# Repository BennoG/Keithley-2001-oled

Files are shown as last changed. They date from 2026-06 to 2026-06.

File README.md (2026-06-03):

# Keithley-2001-oled

This is my attempt to put a OLED display in a Keithley 2001 - 2400 - 7000
This is for the almost unobtainable dot matrix VFD display.

At this moment only tested on a raspberry PI and raspberry PI pico
with a Keithley 2001 meter.

For the font I have added all the display test characters and also the bargrap characters.



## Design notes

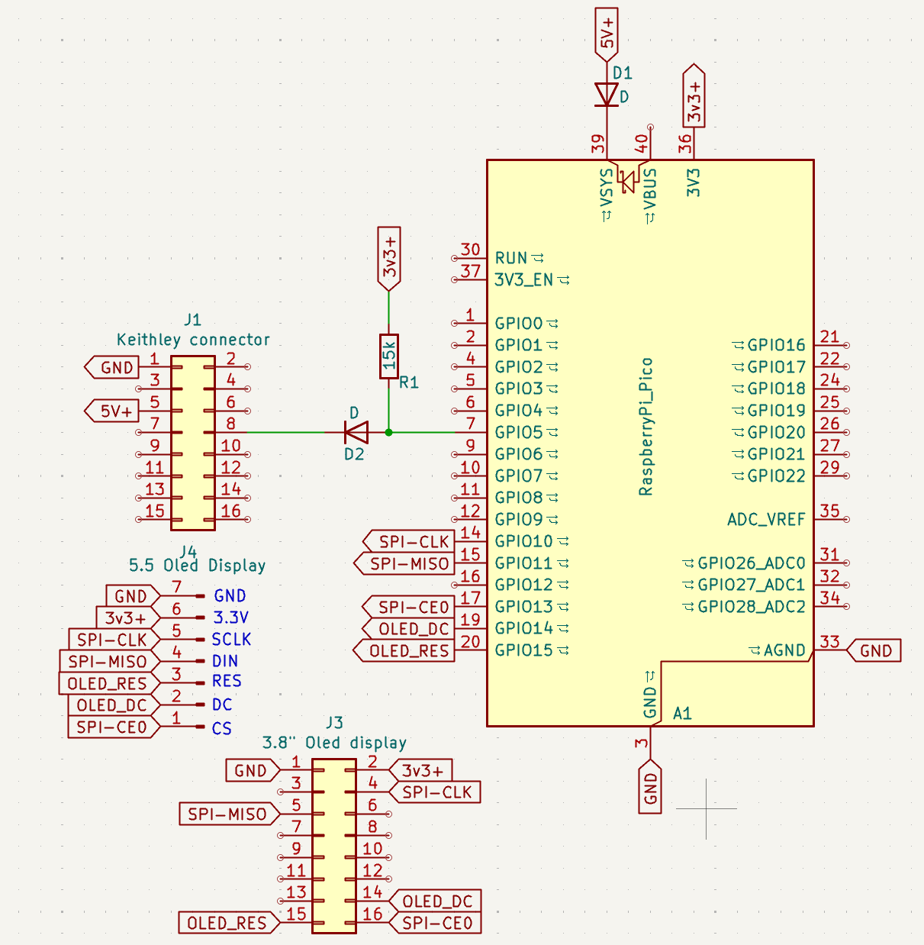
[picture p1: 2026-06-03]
pcb/keithley-2001-display-handwire/simple schema.png

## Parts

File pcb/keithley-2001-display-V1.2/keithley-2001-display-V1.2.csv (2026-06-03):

Reference | Value | Datasheet | Footprint | Qty | DNP | JLCPCB | Sim.Device
A1 | RaspberryPi_Pico | https://datasheets.raspberrypi.com/pico/pico-datasheet.pdf | Module:RaspberryPi_Pico_Common_Unspecified | 1 | DNP | DNP
C1,C2,C4,C5,C6 | 100n/50V |  | Capacitor_SMD:C_0402_1005Metric | 5 |  | C307331 | basic
C3 | 10u 100V |  | Capacitor_SMD:CP_Elec_8x6.2 | 1 |  | C346985 | extended
D1 | B360A-13-F | http://www.farnell.com/datasheets/2238505.pdf | Diode_SMD:D_SMA | 1 |  | C14996 | basic
H1,H2,H3 | MountingHole |  | MountingHole:MountingHole_2.7mm_M2.5 | 3 | DNP | DNP
J1 | Kdisp |  | Connector_PinHeader_2.54mm:PinHeader_2x08_P2.54mm_Vertical | 1 | DNP | DNP
J2 | Kcpu |  | Connector_PinHeader_2.54mm:PinHeader_2x08_P2.54mm_Vertical | 1 | DNP | DNP
J3 | 3.8" Oled display |  | Connector_PinHeader_2.54mm:PinHeader_2x08_P2.54mm_Vertical | 1 | DNP | DNP
J4 | 5.5 Oled Display |  | Connector_PinHeader_2.54mm:PinHeader_1x07_P2.54mm_Vertical | 1 | DNP | DNP
J5 | Conn_01x03_Pin |  | Connector_PinHeader_2.54mm:PinHeader_1x03_P2.54mm_Vertical | 1 | DNP | DNP
R1 | 15k |  | Resistor_SMD:R_0201_0603Metric | 1 |  | C22809 | basic
U1,U3 | 74LVC2T45DC | https://assets.nexperia.com/documents/data-sheet/74LVC_LVCH2T45.pdf | Package_SO:VSSOP-8_2.3x2mm_P0.5mm | 2 |  | C15741 | extended
U2 | 74LVC1G08 | https://www.ti.com/lit/ds/symlink/sn74lvc1g08.pdf | Package_TO_SOT_SMD:SOT-23-5 | 1 |  | C7666 | extended

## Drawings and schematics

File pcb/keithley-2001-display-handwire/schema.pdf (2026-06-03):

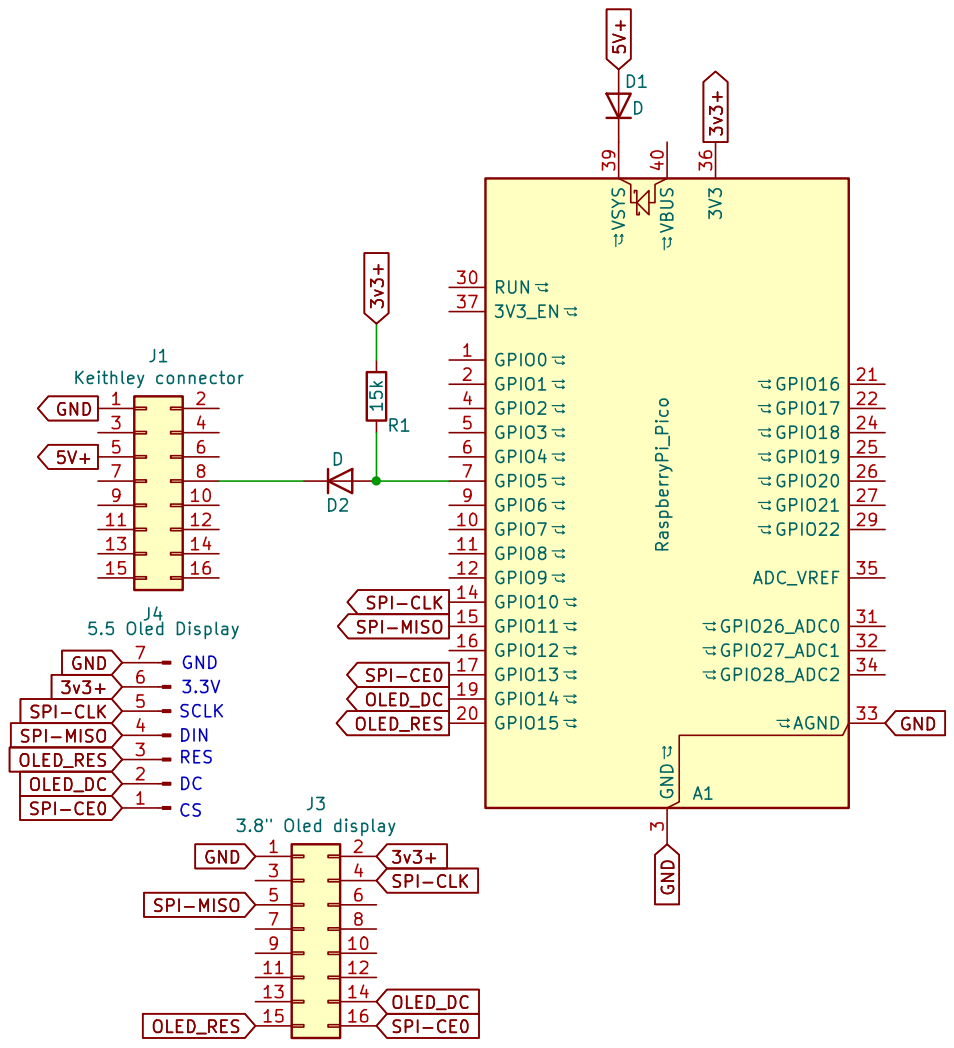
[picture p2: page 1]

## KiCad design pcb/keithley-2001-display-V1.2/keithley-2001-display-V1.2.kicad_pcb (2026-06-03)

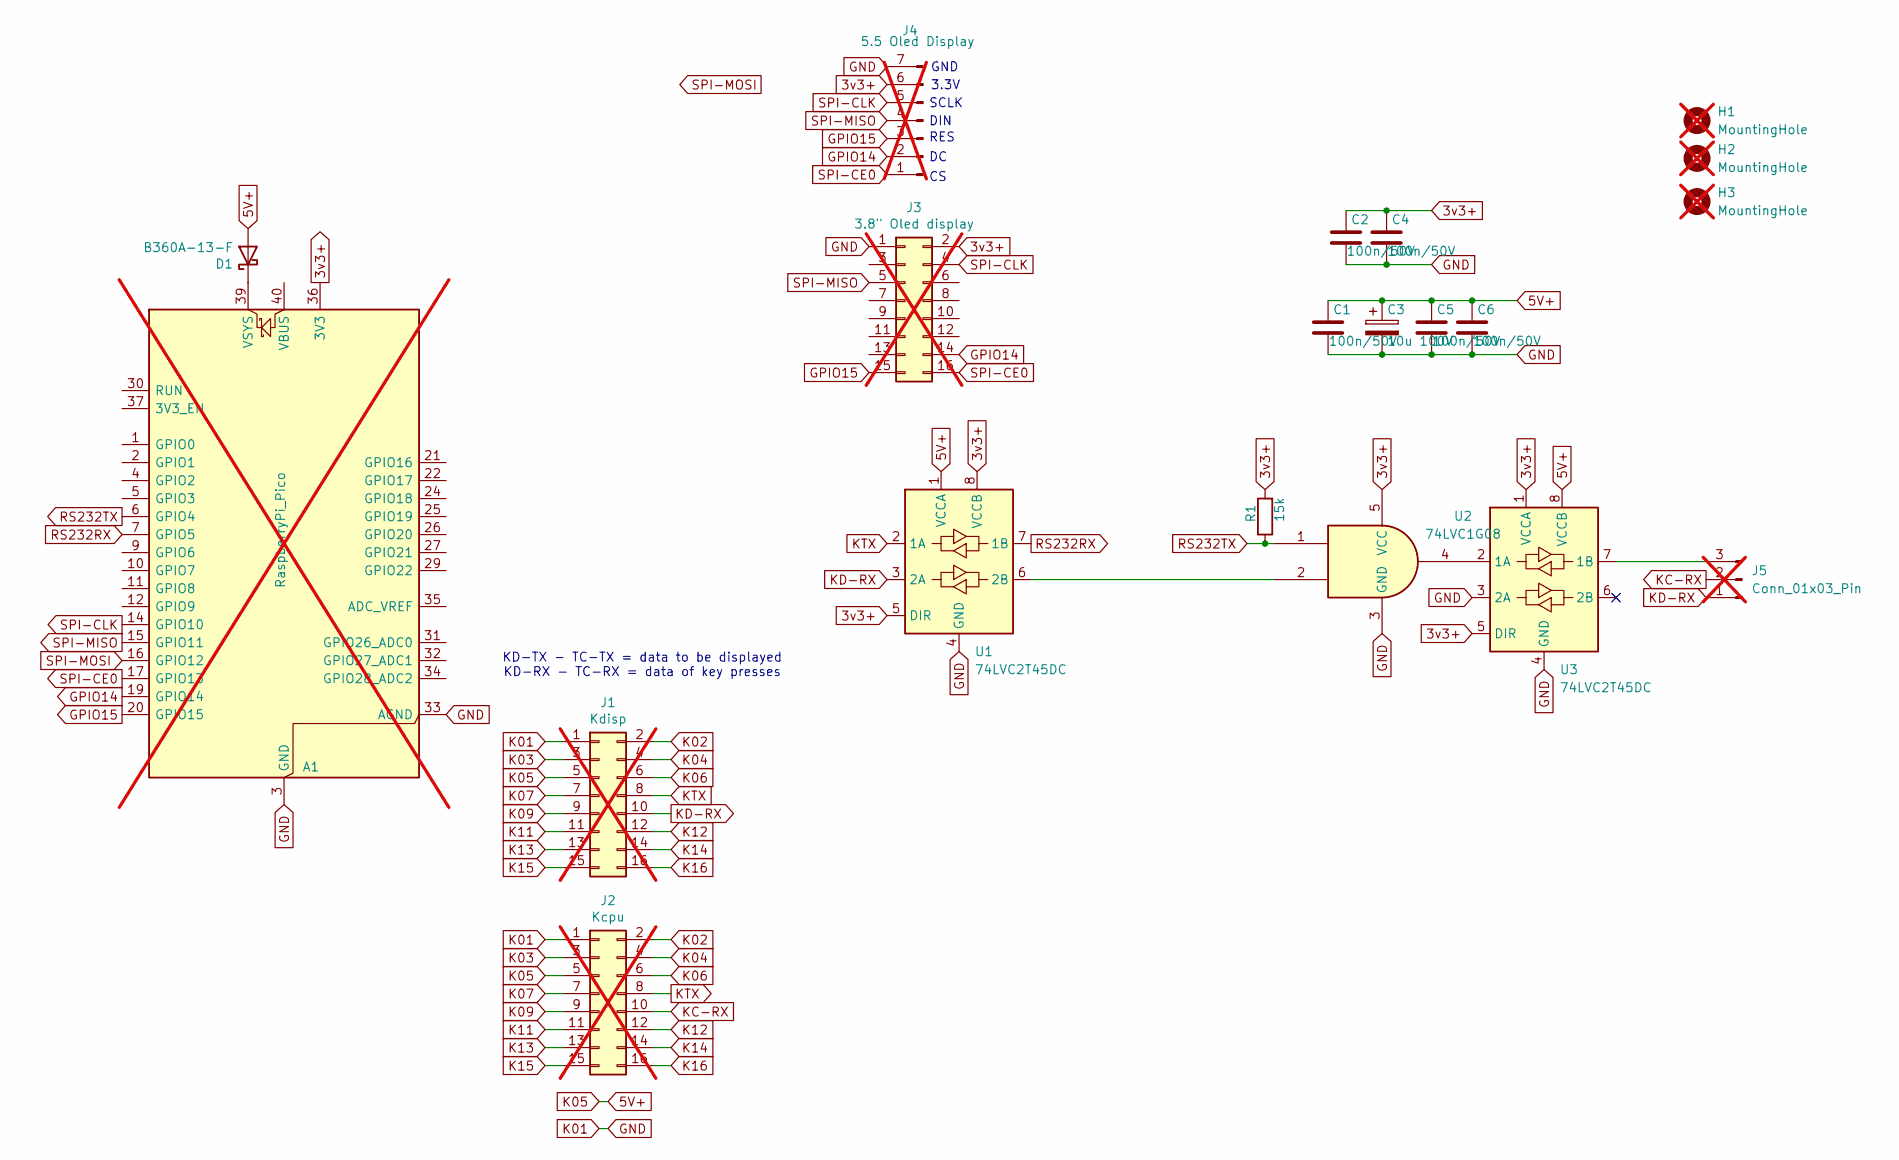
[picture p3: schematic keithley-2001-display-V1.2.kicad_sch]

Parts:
A1: RaspberryPi_Pico; RaspberryPi_Pico_Common_Unspecified; JLCPCB DNP; not fitted
C1, C2, C4, C5, C6: 100n/50V; C_0402_1005Metric; JLCPCB C307331
C3: 10u 100V; CP_Elec_8x6.2; JLCPCB C346985
D1: B360A-13-F; D_SMA; JLCPCB C14996
H1, H2, H3: MountingHole; MountingHole_2.7mm_M2.5; JLCPCB DNP; not fitted
J1: Kdisp; PinHeader_2x08_P2.54mm_Vertical; JLCPCB DNP; not fitted
J2: Kcpu; PinHeader_2x08_P2.54mm_Vertical; JLCPCB DNP; not fitted
J3: 3.8" Oled display; PinHeader_2x08_P2.54mm_Vertical; JLCPCB DNP; not fitted
J4: 5.5 Oled Display; PinHeader_1x07_P2.54mm_Vertical; JLCPCB DNP; not fitted
J5: Conn_01x03_Pin; PinHeader_1x03_P2.54mm_Vertical; JLCPCB DNP; not fitted
R1: 15k; R_0201_0603Metric; JLCPCB C22809
U1, U3: 74LVC2T45DC; VSSOP-8_2.3x2mm_P0.5mm; JLCPCB C15741
U2: 74LVC1G08; SOT-23-5; JLCPCB C7666

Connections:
3v3+: A1.36 (3V3), C2.1, C4.1, J3.2, J4.6, R1.2, U1.5 (DIR), U1.8 (VCCB), U2.5 (VCC), U3.1 (VCCA), U3.5 (DIR)
5V+: C1.1, C3.1, C5.1, C6.1, D1.2 (A), J1.5, J2.5, U1.1 (VCCA), U3.8 (VCCB)
GND: A1.3 (GND), A1.8 (GND), A1.13 (GND), A1.18 (GND), A1.23 (GND), A1.28 (GND), A1.33 (AGND), A1.38 (GND), C1.2, C2.2, C3.2, C4.2, C5.2, C6.2, J1.1, J2.1, J3.1, J4.7, U1.4 (GND), U2.3 (GND), U3.3 (2A), U3.4 (GND)
GPIO14: A1.19 (GPIO14), J3.14, J4.2
GPIO15: A1.20 (GPIO15), J3.15, J4.3
K02: J1.2, J2.2
K03: J1.3, J2.3
K04: J1.4, J2.4
K06: J1.6, J2.6
K07: J1.7, J2.7
K09: J1.9, J2.9
K11: J1.11, J2.11
K12: J1.12, J2.12
K13: J1.13, J2.13
K14: J1.14, J2.14
K15: J1.15, J2.15
K16: J1.16, J2.16
KC-RX: J2.10, J5.2
KD-RX: J1.10, J5.1, U1.3 (2A)
KTX: J1.8, J2.8, U1.2 (1A)
unnamed: A1.39 (VSYS), D1.1 (K)
unnamed: J5.3, U3.7 (1B)
unnamed: U1.6 (2B), U2.2
unnamed: U2.4, U3.2 (1A)
RS232RX: A1.7 (GPIO5), U1.7 (1B)
RS232TX: A1.6 (GPIO4), R1.1, U2.1
SPI-CE0: A1.17 (GPIO13), J3.16, J4.1
SPI-CLK: A1.14 (GPIO10), J3.4, J4.5
SPI-MISO: A1.15 (GPIO11), J3.5, J4.4
SPI-MOSI: A1.16 (GPIO12)

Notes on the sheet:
RES
3.3V
SCLK
GND
KD-TX - TC-TX = data to be displayed KD-RX - TC-RX = data of key presses
DIN

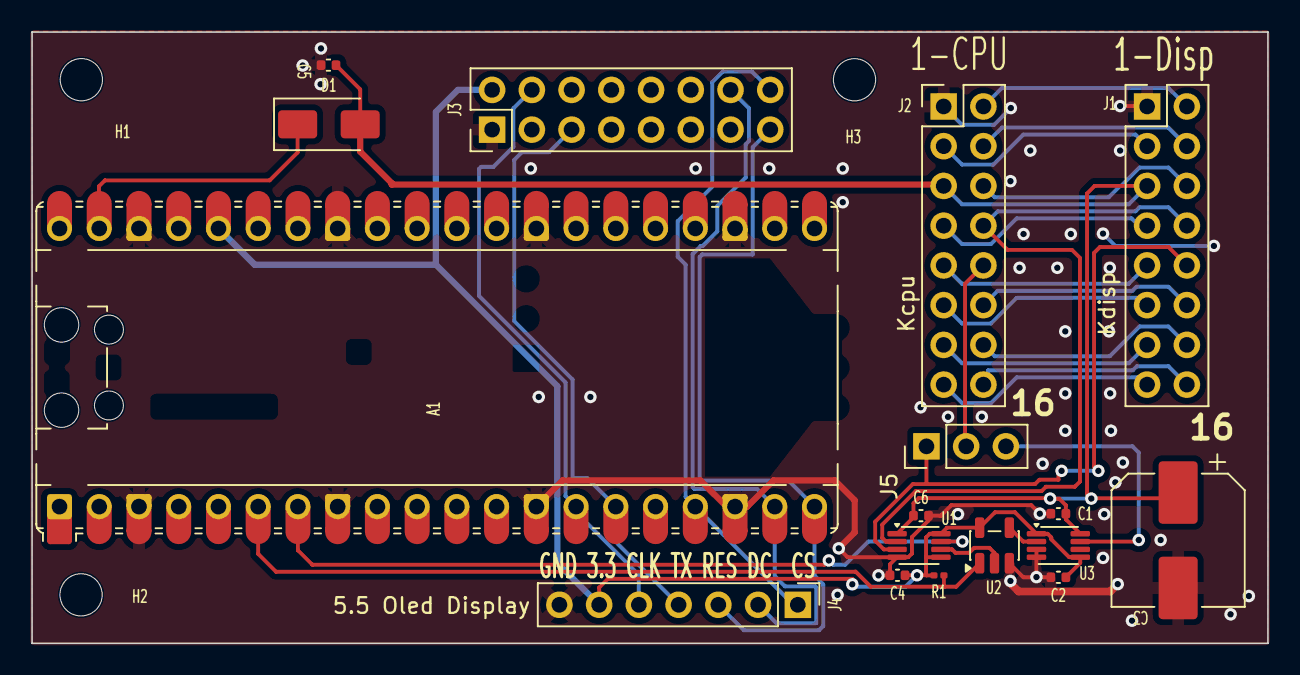
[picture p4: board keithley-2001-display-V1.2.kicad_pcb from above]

Board: 2 copper layers, 79.0 x 39.1 mm, 20 parts (0 on the bottom side), 29 nets.

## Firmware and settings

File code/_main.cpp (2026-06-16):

#include <string>
#include <vector>
#include <cstdlib>
#include <cstring>
#include <cstdint>
#include <stdio.h>

#include "pico/stdlib.h"
#include "hardware/spi.h"
#include "hardware/uart.h"
#include "keithleyDisplay.h"
#include "pico/bootrom.h"
#include "SSD1322.h"
#define PROGMEM
#include "font/calibri5pt7b.h"
#include "font/calibri6pt7b.h"
#include "font/calibri7pt7b.h"
#include "font/calibri8pt7b.h"
//#include "font/NotoMono15pt.h"
#include "font/FreeMono18pt7b.h"
#include "font/FreeMono24pt7b.h"
#include "font/NotoMono_Regular24pt7b.h"
#include "font/NotoMono_Regular22pt7b.h"
#include "font/NotoMono_Regular20pt7b.h"
#include "font/NotoMono_Regular19pt7b.h"
#include "font/NotoMono_Regular18pt7b.h"
#include "font/NotoMono_Regular17pt7b.h"
#include "font/NotoMono_Regular16pt7b.h"
#include "font/NotoMono_Regular15pt7b.h"
#include "font/NotoMono_Regular5pt7b.h"
#include "font/NotoMono_Regular6pt7b.h"
#include "font/NotoMono_Regular7pt7b.h"
#include "font/NotoMono_Regular8pt7b.h"
#include "font/keithleySpecial5x7.h"

int iDebugBits = 0;			// for debugging so we can log different kind of events

// UART defines
// By default the stdout UART is `uart0`, so we will use the second one
#define UART_ID uart1
#define BAUD_RATE 9600

// Use pins 4 and 5 for UART1
// Pins can be changed, see the GPIO function select table in the datasheet for information on GPIO assignments
#define UART_TX_PIN 4
#define UART_RX_PIN 5

static void initHardware() 
{
    stdio_init_all();

    // some pins for debugging with an oscilloscope
    gpio_init(20);
    gpio_init(21);
    gpio_set_dir(20, GPIO_OUT);
    gpio_set_dir(21, GPIO_OUT);

    // Set up our UART
    //uart_set_format(UART_ID,8,1,UART_PARITY_NONE);
    uart_init(UART_ID, BAUD_RATE);
    // Set the TX and RX pins by using the function select on the GPIO
    // Set datasheet for more information on function select
    gpio_set_function(UART_TX_PIN, GPIO_FUNC_UART);
    gpio_set_function(UART_RX_PIN, GPIO_FUNC_UART);
}

class consoleDataHandler
{
    public:
        consoleDataHandler() { initVars(); };
        ~consoleDataHandler() {};
        bool hasSpecialMsg() { return bEscMsgDone; };
        uint32_t getSpecialMsg() { bEscMsgDone = false; return iEscMsg; };
        bool hasCommand(){ return bConMsgDone; };
        int  getCommand(ansStl::cST& msg);
        void poll();
        uint32_t getLastKey() {  uint32_t key = lastReceivedKey; lastReceivedKey = 0; return key; };
    private:
    void initVars() {
        bEscMsgDone = false;
        bConMsgDone = false;
        lastReceivedMS = 0;
        iEscMsg = 0;
        iEscMsgLen = 0;
    }
    ansStl::cST sConMsg;        // for receiving console messages
    ansStl::cST sConMsgLast;    // last received console message, 
    bool bConMsgDone;           // true if a complete console message has been received and is ready for processing
    uint32_t iEscMsg;           // for the special character sequence
    int iEscMsgLen;             // total numer of characters received in the special character sequence
    bool bEscMsgDone;           // true if the special character sequence is complete and ready for processing
    uint32_t lastReceivedMS;	// ms timer last character from the serial port for the special character sequence
    uint32_t lastReceivedKey;   // last keypress we have received
};

int consoleDataHandler::getCommand(ansStl::cST& msg)
{
    if (!bConMsgDone) return 0;
    msg.set(sConMsgLast);
    bConMsgDone = false;
    return msg.length();
}

void consoleDataHandler::poll()
{
    // timeout for the special character sequence is 5 ms, if we have no data for 5ms then we can assume the message is complete
    if (lastReceivedMS != 0)
    {
        uint32_t diffMS = stlMsTimer(lastReceivedMS);
        if ((diffMS > 5) || (iEscMsgLen >= 4)) { bEscMsgDone = true; lastReceivedMS = 0; }
    }
 
    while (true) {
        int c = getchar_timeout_us(0);
        if (c == PICO_ERROR_TIMEOUT) break;
        if (c == 0) continue;   // ignore null characters

        if (lastReceivedMS != 0) {
            if (c == 0x7E) { bEscMsgDone = true; lastReceivedMS = 0; continue; }   // end of special character sequence
            iEscMsg = (iEscMsg << 8) | (c & 0xFF);
            iEscMsgLen++;   
            continue;
        }

        if (c == 0x1B) {   // start of special character sequence
            iEscMsg = 0;
            iEscMsgLen = 1;
            bEscMsgDone = false;
            lastReceivedMS = stlMsTimer(0);
            continue;
        }
        if (c == 0x7F) {   // backspace character, remove last character from the console message
            if (sConMsg.length() > 0){ sConMsg.insDel(-1,-1); putchar(c); }
            //printf("Command='%s'\n", sConMsg.buf());
            continue;
        }
        if ((c == '\n') || (c == '\r')) {
            if (sConMsg.length() > 0 )
            {
                printf("\r\nReceived message: %s\n", sConMsg.buf());
                if (sConMsg.comparei("boot")) reset_usb_boot(0, 0);
                sConMsgLast.set(sConMsg);
                sConMsg.clear();
                bConMsgDone = true;
            }
            continue;
        } else{
            sConMsg.append((char)c);
            //printf("\r%s",sConMsg.buf());
            putchar(c);
        } 
    }
}



static void printHelp()
{
    printf("Possible commands\r\n");
    printf("  boot    reboot in boot mode\r\n");
    printf("  dump    dump last 4000 received chars\r\n");
    printf("  debug [val] debug bits get or set\r\n");
    printf("  debughelp   show all possible debug flags\r\n");
    printf("\r\n");
}

static void handleDebugHelp()
{
    printf("debug 1h   show received display messages\r\n");
    printf("debug 2h   also show stored lengths\r\n");
    printf("debug 4h   do anti alias on the whole screen\r\n");
    printf("debug 8h   drop GPIO20 before sending SPI\r\n");
}

static void handleDebug(ansStl::cST &cmdLin)
{
    ansStl::cST val = cmdLin.getDlm(2,' '); // substr(5, 10);
    if (val.comparei("help")) { handleDebugHelp(); return; }
    if (val.length() > 0)
    {
        iDebugBits =  val.toInt(); //  trtol(val.buf(),NULL,0); //atoi(val.buf());
    }
    printf("debug %d 0x%X\r\n", iDebugBits, iDebugBits);
}

/* handle all commands or characters recieved from the console
** so the user can interact with the program via the console, for example to trigger a reset to boot mode or to send commands to the Keithley display
*/
void handleConsoleData(consoleDataHandler& KH,keithleyDisplay& KD)
{
    KH.poll();
    if (KH.hasSpecialMsg()) {
        uint32_t msg = KH.getSpecialMsg();
        printf("Received special message: 0x%08X\n", msg);
        if (msg == 0x005B3131) reset_usb_boot(0, 0);   // F1 key sequence (go to boot mode) 
    }
    if (KH.hasCommand()) {
        ansStl::cST cmdLin,cmd;
        KH.getCommand(cmdLin);
        cmd = cmdLin.getDlm(1, ' ');
        printf("Received command: %s\r\n", cmdLin.buf());
        if (cmd.comparei("boot")) reset_usb_boot(0, 0);
        else if (cmd.comparei("dump")) KD.saveBuffer(cmdLin.getDlm(2, ' ').toInt());
        else if (cmd.comparei("help")) printHelp();
        else if (cmd.startsWith("debughelp",false)) handleDebugHelp();
        else if (cmd.startsWith("debug",false)) handleDebug(cmdLin);
        else printf("Unknown command type help for commands\r\n");
    }
}


int main()
{
    initHardware();
 
    consoleDataHandler KH;
    keithleyDisplay KD(UART_ID);
	SSD1322 oled;
	oled.init();
    oled.clear();
    KD.iDeviceType = 2001;
    oled.curFontSspec = &keithleySpecial5x7;
    //oled.curFontB = &NotoMono_Regular18pt7b;    // 25 pixels high
    //oled.curFontB = &NotoMono_Regular24pt7b;    // 25 pixels high
    //oled.curFontBhigh = 25;

    uint8_t loopTel = 0;

	ansStl::cST msgHD;		// head row text
	ansStl::cST msgFT;		// footer row text
	ansStl::cST msgValue;	// value text
	bool doRedraw = false;
	uint32_t lastFlipMS = stlMsTimer(0);

    while (true) {
        loopTel++;
   
        // process any incoming data from the Keithley display
        KD.poll();
        // process any incoming data from the console (USB uart)
        handleConsoleData(KH, KD);
             
		if (KD.hasUpdate())
		{
			msgHD = KD.getDispHeadTxts();
			msgFT = KD.getUpdate();				    // both lines (values and 2nd row)
            // the K2000 has 15 chars on the main row
            // the K2001 (7001) has 20 on the first row and 32 on the 2nd, both lines are transmitted in 1 single message
            if (msgFT.length() > 0)
            {
                msgValue = msgFT.substr(0, 20);		// big digits
                msgFT.insDel(0, -20);				// bottom line is remainder
                doRedraw = true;
            }
		}

        // handle flashing of characters if needed and redraw the display
        uint32_t difMS = stlMsTimer(lastFlipMS);
		if ((msgValue.length() > 0) && (difMS > 200u) && (KD.isFlashing()))
		{
			if (difMS < 1000u) difMS = 200;		// so we have a stable flash time
			lastFlipMS += difMS;
			oled.colorFlash = oled.colorFlash == 2 ? 15 : 2;
			doRedraw = true;
		}

        // redraw the display if we have received new data or if we need to update the flashing of characters
        // in the fastest mode we have about 25 ms per display upat to do the update
        // 15.3 ms update time for the 18pt font with AA
        // 11.5 ms update time for the 18pt font without AA
		if (doRedraw)
		{
			doRedraw = false;
            gpio_put(20, 1);                                    // GPIO 20 high for scope timing measurement
			oled.clear();
            if (KD.iDeviceType == 2001)
            {
                oled.curFontB = &NotoMono_Regular16pt7b;            // 25 pixels high
                oled.curFontBhigh = 25;
                int x = 128 - msgHD.length() * 3;                   // calculate the starting position of head text so it is in the horizontal center
                oled.drawString(x, 0, msgHD.buf(), 8, 0);			// top line (ARM AUTO..) text
                oled.drawStringB(4, 32-(oled.curFontBhigh/2), msgValue.buf(), 10, 0, -2);	// values text
                if (iDebugBits & 4)
                    oled.fastAA(19,49);                             // 4.5ms do anti aliassing on the whole screen (can be reduced if we onlo do the lines of the big chars)
                oled.hLine(0,22,50,8);
                oled.hLine(0,47,50,8);
                oled.drawString(2, 55, msgFT.buf(), 8, 0, 2);		// bottom line somewhat wider chars
                if (iDebugBits & 8) gpio_put(20, 0);                // debug 0x008 lower GPIO20 before sending the SPI screen data
            }else{
                oled.curFontB = &NotoMono_Regular20pt7b;            // 30 pixels high
                oled.curFontBhigh = 30;
                oled.drawStringB(4, 32-(oled.curFontBhigh/2), msgValue.buf(), 10, 0, -3);	// values text
                if (iDebugBits & 4)
                    oled.fastAA(19,49);                             // 4.5ms full and 3.7ms partial anti aliassing
                //oled.hLine(0,19,50,8);
                //oled.hLine(0,49,50,8);

                int x = 128 - msgHD.length() * 3;                   // calculate the starting position of head text so it is in the horizontal center
                oled.drawString(x, 0, msgHD.buf(), 8, 0);			// top line (ARM AUTO..) text
                //msgFT.clear(); msgFT.append("\x10\x11\x12\x13\x14\x15\x16\x17\x18\x19\x1A\x1B\x1C\x1D\x1E\x1F");
                //oled.drawString(2, 55, msgFT.buf(), 8, 0, 0);   // bottom line somewhat wider chars
                //msgFT.set(" !\"#$%&'()*+,-./012345");
                //oled.drawString(&keithleySpecial5x7,128, 55, msgFT.buf(), 8, 0, 0);   // bottom line somewhat wider chars
                //oled.drawString(&keithleySpecial5x7,94, 55, "-./0", 8, 0, 0);   // bottom line somewhat wider chars
                if (iDebugBits & 8) gpio_put(20, 0);                // debug 0x008 lower GPIO20 before sending the SPI screen data
            }

			oled.update();                                          // 9.0 ms redraw screen from memeory this takes about 9 ms
            gpio_put(20, 0);
        }
        gpio_put(21, loopTel & 1);      // toggle pin to measure loop time with an oscilloscope
    }
}

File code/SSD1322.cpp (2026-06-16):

#ifndef _WIN32

#if defined(PICO_RP2040)

#else
#  include <linux/spi/spidev.h>
#  include <sys/ioctl.h>
#endif

#include <iostream>
#include <fcntl.h>
#include <unistd.h>
#include <fstream>
#include <thread>

extern int iDebugBits;			// for debugging so we can log different kind of events (defined in main.cpp)

#include "SSD1322.h"

// --- SSD1322 Commands ---------------------------------------------------------
enum SSD1322Cmd : uint8_t {
	CMD_SET_COL_ADDR = 0x15,
	CMD_WRITE_RAM = 0x5C,
	CMD_READ_RAM = 0x5D,
	CMD_SET_ROW_ADDR = 0x75,
	CMD_SET_REMAP = 0xA0,
	CMD_SET_DISPLAY_START = 0xA1,
	CMD_SET_DISPLAY_OFFSET = 0xA2,
	CMD_DISPLAY_NORMAL = 0xA4,   // show GDDRAM content
	CMD_DISPLAY_ALL_ON = 0xA5,
	CMD_DISPLAY_ALL_OFF = 0xA6,
	CMD_DISPLAY_INVERT = 0xA7,
	CMD_SET_MUX_RATIO = 0xCA,
	CMD_SET_GPIO = 0xB5,
	CMD_SET_FUNC_SEL = 0xAB,
	CMD_SET_PHASE_LEN = 0xB1,
	CMD_SET_CLK_DIV = 0xB3,
	CMD_SET_VSL = 0xB4,
	CMD_SET_GRAY_SCALE = 0xB8,
	CMD_DEFAULT_GRAY_SCALE = 0xB9,
	CMD_SET_PRECHARGE_V = 0xBB,
	CMD_SET_VCOMH = 0xBE,
	CMD_SET_CONTRAST = 0xC1,
	CMD_MASTER_CONTRAST = 0xC7,
	CMD_SET_PRECHARGE_2 = 0xD1,  // actually 0xB6 on some docs; use 0xB6
	CMD_SET_PRECHARGE2 = 0xB6,
	CMD_SLEEP_ON = 0xAE,	// display off
	CMD_SLEEP_OFF = 0xAF,	// display on
	CMD_ENHANCE_A = 0xB4,  // overlaps VSL; see usage in init
};

// example for exclamation mark '!' (0x21):
// 01  X
// 02  X
// 04  X
// 08  X
// 10  X
// 20
// 40  X
// 80

const uint8_t k2001Remap[][2]
{
	// original - replacement special font
	{ 0x10,0x20 },	// 0x10		B5 u (micro)
	{ 0x11,0x21 },	// 0x11
	{ 0x12,0x22 },	// 0x12     AF Ohm (Omega)
	{ 0x13,0x23 },	// 0x13     B0 o (Celsius degree)
	{ 0x14,0x24 },	// 0x14     bar graph stand left block
	{ 0x15,0x25 },	// 0x15     bar graph stand right block
	{ 0x16,0x26 },	// 0x16     bar graph mid bard
	{ 0x17,0x27 },	// 0x17     bar graph left block
	{ 0x18,0x28 },	// 0x18     bar graph right block
	{ 0x19,0x29 },	// 0x19     bar graph  block
	{ 0x1A,0x2A },	// 0x1A     ^ up arrow
	{ 0x1B,0x2B },	// 0x1B     v down arrow
	{ 0x1C,0x2C },	// 0x1C		< left arrow
	{ 0x1D,0x2D },	// 0x1D     > rithg arrow
	{ 0x1E,0x2E },	// 0x1E		display test pattern
	{ 0x1F,0x2F },	// 0x1F     display test pattern

	{ 0x90,0x20 },	// 0x90  horizontal top line
	{ 0x91,0x21 },	// 0x91  horizontal 2nd line
	{ 0x92,0x22 },	// 0x92  horizontal 3th line
	{ 0x93,0x23 },	// 0x93  horizontal 4th line
	{ 0x94,0x24 },	// 0x94  horizontal 5th line
	{ 0x95,0x25 },	// 0x95  horizontal 6th line
	{ 0x96,0x26 },	// 0x96  horizontal bottom line
	{ 0x97,0x27 },	// 0x97  vertical left
	{ 0x98,0x28 },	// 0x98  vertical 2nd
	{ 0x99,0x29 },	// 0x99  vertical 3th
	{ 0x9A,0x2A },	// 0x9A  vertical 4th
	{ 0x9B,0x2B },	// 0x9B  vertical right
	{ 0x9C,0x2C },	// 0x9C  Up and Down arrow
};



const uint8_t font5x7L[][5] = {	// k7001 display special characters 0x00 - 0x9F Below 0x20 and above 0x7F are mostly blank, but some are used for special symbols and bar graph elements
	{0x00,0x00,0x00,0x00,0x00}, // ' '
	{0x00,0x00,0x5F,0x00,0x00}, // '!'
	{0x00,0x07,0x00,0x07,0x00}, // '"'
	{0x14,0x7F,0x14,0x7F,0x14}, // '#'
	{0x24,0x2A,0x7F,0x2A,0x12}, // '$'
	{0x23,0x13,0x08,0x64,0x62}, // '%'
	{0x36,0x49,0x55,0x22,0x50}, // '&'
	{0x00,0x05,0x03,0x00,0x00}, // '\''
	{0x00,0x1C,0x22,0x41,0x00}, // '('
	{0x00,0x41,0x22,0x1C,0x00}, // ')'
	{0x14,0x08,0x3E,0x08,0x14}, // '*'
	{0x08,0x08,0x3E,0x08,0x08}, // '+'
	{0x00,0x50,0x30,0x00,0x00}, // ','
	{0x08,0x08,0x08,0x08,0x08}, // '-'
	{0x00,0x60,0x60,0x00,0x00}, // '.'
	{0x20,0x10,0x08,0x04,0x02}, // '/'
	{0x3E,0x51,0x49,0x45,0x3E}, // '0'
	{0x00,0x42,0x7F,0x40,0x00}, // '1'
	{0x42,0x61,0x51,0x49,0x46}, // '2'
	{0x21,0x41,0x45,0x4B,0x31}, // '3'
	{0x18,0x14,0x12,0x7F,0x10}, // '4'
	{0x27,0x45,0x45,0x45,0x39}, // '5'
	{0x3C,0x4A,0x49,0x49,0x30}, // '6'
	{0x01,0x71,0x09,0x05,0x03}, // '7'
	{0x36,0x49,0x49,0x49,0x36}, // '8'
	{0x06,0x49,0x49,0x29,0x1E}, // '9'
	{0x00,0x36,0x36,0x00,0x00}, // ':'
	{0x00,0x56,0x36,0x00,0x00}, // ';'
	{0x08,0x14,0x22,0x41,0x00}, // '<'
	{0x14,0x14,0x14,0x14,0x14}, // '='
	{0x00,0x41,0x22,0x14,0x08}, // '>'
	{0x02,0x01,0x51,0x09,0x06}, // '?'
	{0x32,0x49,0x79,0x41,0x3E}, // '@'
	{0x7E,0x11,0x11,0x11,0x7E}, // 'A'
	{0x7F,0x49,0x49,0x49,0x36}, // 'B'
	{0x3E,0x41,0x41,0x41,0x22}, // 'C'
	{0x7F,0x41,0x41,0x22,0x1C}, // 'D'
	{0x7F,0x49,0x49,0x49,0x41}, // 'E'
	{0x7F,0x09,0x09,0x09,0x01}, // 'F'
	{0x3E,0x41,0x49,0x49,0x7A}, // 'G'
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
	{0x7F,0x7F,0x7F,0x7F,0x7F}, // 7F DEL (placeholder)
};

SSD1322::SSD1322()
{
	initVars();
}

SSD1322::~SSD1322()
{
}

void SSD1322::init() 
{
	openSPI();
	openGPIO();
	reset();
	initSequence();
	clear();
	update();
}

void SSD1322::close() 
{
	#if defined(PICO_RP2040)
	#else
	if (spi_fd_ >= 0) { ::close(spi_fd_); spi_fd_ = -1; }
	if (line_dc_) { gpiod_line_release(line_dc_);  line_dc_ = nullptr; }
	if (line_rst_) { gpiod_line_release(line_rst_); line_rst_ = nullptr; }
	if (chip_) { gpiod_chip_close(chip_);       chip_ = nullptr; }
	#endif
}

// -- Framebuffer access ----------------------------------------------------

// Clear framebuffer to given 4-bit gray level (0x15)
void SSD1322::clear(uint8_t gray /* = 0 */) 
{
	uint8_t byte = ((gray & 0x0F) << 4) | (gray & 0x0F);
	std::fill(fb_.begin(), fb_.end(), byte);
}

// Set individual pixel, x: 0-255, y: 0-63, gray: 0-15
void SSD1322::setPixel(int x, int y, uint8_t gray) 
{
	if (x < 0 || x >= DISPLAY_WIDTH || y < 0 || y >= DISPLAY_HEIGHT) return;
	gray &= 0x0F;
	size_t idx = y * (DISPLAY_WIDTH / 2) + x / 2;
	if (x & 1)
		fb_[idx] = (fb_[idx] & 0xF0) | gray;         // low nibble = right pixel
	else
		fb_[idx] = (fb_[idx] & 0x0F) | (gray << 4);  // high nibble = left pixel
}
void SSD1322::aaPixel(int x, int y,uint8_t gray)
{
	if (getPixel(x, y) == gray)
		return;
	bool g1 = getPixel(x - 1, y) == gray;
	bool g2 = getPixel(x, y - 1) == gray;
	bool g3 = getPixel(x + 1, y) == gray;
	bool g4 = getPixel(x, y + 1) == gray;
	if ((g1 && g2) || (g2 && g3) || (g3 && g4) || (g4 && g1))
		setPixel(x, y, gray / 2);
}

void SSD1322::fastAA(int y1, int y2)
{
	int dwh = DISPLAY_WIDTH / 2;
	if (y1 < 0) y1 = 0;
	if (y1 > DISPLAY_HEIGHT) return;
	if (y2 < 0) y2 = DISPLAY_HEIGHT;
	if (y2 > DISPLAY_HEIGHT) y2 = DISPLAY_HEIGHT;
	if (y1 > y2) return;
	int idxStart = y1 * dwh;
	int idxEinde = (y2 + 1) * dwh;
	if (idxEinde > fb_.size()) idxEinde = fb_.size();

	uint8_t grsOld = fb_[idxStart];
	for (int i = idxStart + 1; i < idxEinde; i++)
	{
		uint8_t grsNew = fb_[i];
		if (grsNew == grsOld) continue;
		int y = i / dwh;
		int x = (i % dwh) * 2;
		uint8_t g1 = (grsOld >> 4);
		uint8_t g2 = grsOld & 0xF;
		uint8_t g3 = (grsNew >> 4);
		uint8_t g4 = grsNew & 0xF;
		grsOld = grsNew;
		if ((g1 == 0) && (g2 > 0))	aaPixel(x - 2, y, g2);
		if (g2 == 0)
		{
			if (g1 > 0) aaPixel(x - 1, y, g1);
			else if (g3 > 0) aaPixel(x - 1, y, g3);
		}
		if (g3 == 0)
		{
			if (g2 > 0) aaPixel(x , y, g2);
			else if (g4 > 0) aaPixel(x , y, g4);
		}
		if ((g4 == 0) && (g3 > 0)) aaPixel(x + 1 , y, g3);
	}
}
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

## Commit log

2026-06-03 added pcb and wiring diagrams
    [keithley-2001-display-V1.2.csv, keithley-2001-display-V1.2.kicad_pcb, keithley-2001-display-V1.2.kicad_sch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]
2026-06-03 Gerber files added for this PCB
    [keithley-2001-display-V1.2-bottom-pos.csv, keithley-2001-display-V1.2-top-pos-JLC.csv, keithley-2001-display-V1.2-top-pos.csv]
